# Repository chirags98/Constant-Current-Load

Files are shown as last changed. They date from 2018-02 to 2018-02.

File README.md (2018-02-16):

# Constant-Current-Load

This circuit uses an opamp and a mosfet as a voltage follower circuit. I can dial in any current I want and the circuit will adjust itself to draw that much current from the power supply regardless of the supply voltage. It can be 3 Volts, 5 Volts, 15 Volts whatever it might be and the load will adjust itself to draw the selected current.

This is a double sided board design which I got manufactured from a PCB prototyping firm in China.

I designed the circuit to have the following features

* To have a knob to vary the current from 1mA-2A
* Dissipate upto 30 watts of power
* Connect a supply upto 30 volts
* To have a LCD panel to show 
    * Current drawn
    * Voltage across the load
    * Power dissipated in the load
* Give warnings if power/current/voltage range are excedded
* Give the user the choice to run the circuit from the load supply thereby eliminating the need for an external power supply

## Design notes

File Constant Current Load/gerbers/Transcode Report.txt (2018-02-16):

   ---- Transcoding 'E:\EAGLE 8.2.2\My projects\Constant-Current-Load\Constant Current Load\gerbers\load.GBS' ----   Tue Sep 12 23:22:22 2017

D10   --> D100
D11   --> D101
D12   --> D102
D13   --> D103
D14   --> D104
D15   --> D105
D16   --> D106
D17   --> D107
D18   --> D108
D19   --> D109
D20   --> D110
D21   --> D111
D22   --> D112
D23   --> D113
D24   --> D114
D25   --> D115
D26   --> D116
D27   --> D117
-----------------------------------------------------------------

   ---- Transcoding 'E:\EAGLE 8.2.2\My projects\Constant-Current-Load\Constant Current Load\gerbers\load.GTL' ----   Tue Sep 12 23:22:22 2017

D10   --> D118
D11   --> D119
D12   --> D120
D13   --> D121
D14   --> D122
D15   --> D123
D16   --> D124
D17   --> D125
D18   --> D126
D19   --> D127
D20   --> D128
D21   --> D129
D22   --> D130
D23   --> D131
D24   --> D132
D25   --> D133
D26   --> D134
D27   --> D135
D28   --> D136
D29   --> D137
-----------------------------------------------------------------

   ---- Transcoding 'E:\EAGLE 8.2.2\My projects\Constant-Current-Load\Constant Current Load\gerbers\load.GTO' ----   Tue Sep 12 23:22:22 2017

D10   --> D138
D11   --> D139
D12   --> D140
D13   --> D141
D14   --> D142
D15   --> D143
D16   --> D144
D17   --> D145
D18   --> D146
D19   --> D147
D20   --> D148
D21   --> D149
D22   --> D150
D23   --> D151
D24   --> D152
-----------------------------------------------------------------

   ---- Transcoding 'E:\EAGLE 8.2.2\My projects\Constant-Current-Load\Constant Current Load\gerbers\load.GTS' ----   Tue Sep 12 23:22:22 2017

D10   --> D153
D11   --> D154
D12   --> D155
D13   --> D156
D14   --> D157
D15   --> D158
D16   --> D159
D17   --> D160
D18   --> D161
D19   --> D162
D20   --> D163
D21   --> D164
D22   --> D165
D23   --> D166
D24   --> D167
D25   --> D168
D26   --> D169
D27   --> D170
D28   --> D171
D29   --> D172
D30   --> D173
D31   --> D174
-----------------------------------------------------------------

   ---- Transcoding 'E:\EAGLE 8.2.2\My projects\Constant-Current-Load\Constant Current Load\gerbers\load.GBS' ----   Tue Sep 12 23:25:59 2017

D10   --> D100
D11   --> D101
D12   --> D102
D13   --> D103
D14   --> D104
D15   --> D105
D16   --> D106
D17   --> D107
D18   --> D108
D19   --> D109
D20   --> D110
D21   --> D111
D22   --> D112
D23   --> D113
D24   --> D114
D25   --> D115
D26   --> D116
D27   --> D117
-----------------------------------------------------------------

   ---- Transcoding 'E:\EAGLE 8.2.2\My projects\Constant-Current-Load\Constant Current Load\gerbers\load.GTL' ----   Tue Sep 12 23:25:59 2017

D10   --> D118
D11   --> D119
D12   --> D120
D13   --> D121
D14   --> D122
D15   --> D123
D16   --> D124
D17   --> D125
D18   --> D126
D19   --> D127
D20   --> D128
D21   --> D129
D22   --> D130
D23   --> D131
D24   --> D132
D25   --> D133
D26   --> D134
D27   --> D135
D28   --> D136
D29   --> D137
-----------------------------------------------------------------

   ---- Transcoding 'E:\EAGLE 8.2.2\My projects\Constant-Current-Load\Constant Current Load\gerbers\load.GTO' ----   Tue Sep 12 23:26:00 2017

D10   --> D138
D11   --> D139
D12   --> D140
D13   --> D141
D14   --> D142
D15   --> D143
D16   --> D144
D17   --> D145
D18   --> D146
D19   --> D147
D20   --> D148
D21   --> D149
D22   --> D150
D23   --> D151
D24   --> D152
-----------------------------------------------------------------

   ---- Transcoding 'E:\EAGLE 8.2.2\My projects\Constant-Current-Load\Constant Current Load\gerbers\load.GTS' ----   Tue Sep 12 23:26:00 2017

D10   --> D153
D11   --> D154
D12   --> D155
D13   --> D156
D14   --> D157
D15   --> D158
D16   --> D159
D17   --> D160
D18   --> D161
D19   --> D162
D20   --> D163
D21   --> D164
D22   --> D165
D23   --> D166
D24   --> D167
D25   --> D168
D26   --> D169
D27   --> D170
D28   --> D171
D29   --> D172
D30   --> D173
D31   --> D174
-----------------------------------------------------------------

   ---- Transcoding 'E:\EAGLE 8.2.2\My projects\Constant-Current-Load\Constant Current Load\gerbers\load.GBS' ----   Tue Sep 12 23:31:38 2017

D10   --> D100
D11   --> D101
D12   --> D102
D13   --> D103
D14   --> D104
D15   --> D105
D16   --> D106
D17   --> D107
D18   --> D108
D19   --> D109
D20   --> D110
D21   --> D111
D22   --> D112
D23   --> D113
D24   --> D114
D25   --> D115
D26   --> D116
D27   --> D117
-----------------------------------------------------------------

   ---- Transcoding 'E:\EAGLE 8.2.2\My projects\Constant-Current-Load\Constant Current Load\gerbers\load.GTL' ----   Tue Sep 12 23:31:38 2017

D10   --> D118
D11   --> D119
D12   --> D120
D13   --> D121
D14   --> D122
D15   --> D123
D16   --> D124
D17   --> D125
D18   --> D126
D19   --> D127
D20   --> D128
D21   --> D129
D22   --> D130
D23   --> D131
D24   --> D132
D25   --> D133
D26   --> D134
D27   --> D135
D28   --> D136
D29   --> D137
-----------------------------------------------------------------

   ---- Transcoding 'E:\EAGLE 8.2.2\My projects\Constant-Current-Load\Constant Current Load\gerbers\load.GTO' ----   Tue Sep 12 23:31:38 2017

D10   --> D138
D11   --> D139
D12   --> D140
D13   --> D141
D14   --> D142
D15   --> D143
D16   --> D144
D17   --> D145
D18   --> D146
D19   --> D147
D20   --> D148
D21   --> D149
D22   --> D150
D23   --> D151
D24   --> D152
-----------------------------------------------------------------

   ---- Transcoding 'E:\EAGLE 8.2.2\My projects\Constant-Current-Load\Constant Current Load\gerbers\load.GTS' ----   Tue Sep 12 23:31:38 2017

D10   --> D153
D11   --> D154
D12   --> D155
D13   --> D156
D14   --> D157
D15   --> D158
D16   --> D159
D17   --> D160
D18   --> D161
D19   --> D162
D20   --> D163
D21   --> D164
D22   --> D165
D23   --> D166
D24   --> D167
D25   --> D168
D26   --> D169
D27   --> D170
D28   --> D171
D29   --> D172
D30   --> D173
D31   --> D174
-----------------------------------------------------------------

   ---- Transcoding 'E:\EAGLE 8.2.2\My projects\Constant-Current-Load\Constant Current Load\gerbers\load.GBS' ----   Tue Sep 12 23:42:00 2017

D10   --> D100
D11   --> D101
D12   --> D102
D13   --> D103
D14   --> D104
D15   --> D105
D16   --> D106
D17   --> D107
D18   --> D108
D19   --> D109
D20   --> D110
D21   --> D111
D22   --> D112
D23   --> D113
D24   --> D114
D25   --> D115
D26   --> D116
D27   --> D117
-----------------------------------------------------------------

   ---- Transcoding 'E:\EAGLE 8.2.2\My projects\Constant-Current-Load\Constant Current Load\gerbers\load.GTL' ----   Tue Sep 12 23:42:01 2017

D10   --> D118
D11   --> D119
D12   --> D120
D13   --> D121
D14   --> D122
D15   --> D123
D16   --> D124
D17   --> D125
D18   --> D126
D19   --> D127
D20   --> D128
D21   --> D129
D22   --> D130
D23   --> D131
D24   --> D132
D25   --> D133
D26   --> D134
D27   --> D135
D28   --> D136
D29   --> D137
-----------------------------------------------------------------

   ---- Transcoding 'E:\EAGLE 8.2.2\My projects\Constant-Current-Load\Constant Current Load\gerbers\load.GTO' ----   Tue Sep 12 23:42:01 2017

D10   --> D138
D11   --> D139
D12   --> D140
D13   --> D141
D14   --> D142
D15   --> D143
D16   --> D144
D17   --> D145
D18   --> D146
D19   --> D147
D20   --> D148
D21   --> D149
D22   --> D150
D23   --> D151
-----------------------------------------------------------------

   ---- Transcoding 'E:\EAGLE 8.2.2\My projects\Constant-Current-Load\Constant Current Load\gerbers\load.GTS' ----   Tue Sep 12 23:42:01 2017

D10   --> D152
D11   --> D153
D12   --> D154
D13   --> D155
D14   --> D156
D15   --> D157
D16   --> D158
D17   --> D159
D18   --> D160
D19   --> D161
D20   --> D162
D21   --> D163
D22   --> D164
D23   --> D165
D24   --> D166
D25   --> D167
D26   --> D168
D27   --> D169
D28   --> D170
D29   --> D171
D30   --> D172
D31   --> D173
-----------------------------------------------------------------

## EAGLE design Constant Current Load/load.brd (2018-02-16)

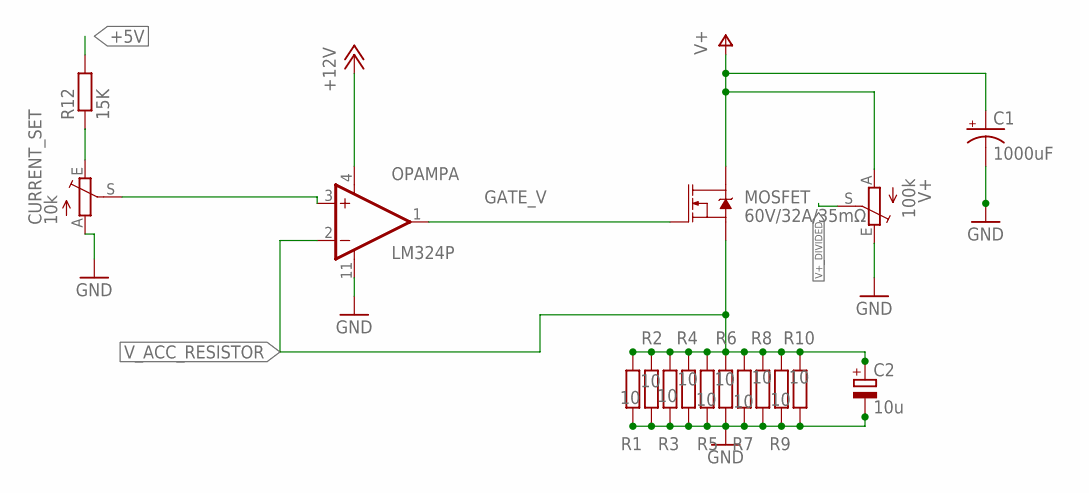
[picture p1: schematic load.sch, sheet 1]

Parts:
C1: 1000uF; CPOL-RADIAL-5MM-10MM
C2: 10u; E2,5-6E
CURRENT_SET: 10k; S64W
MOSFET: 60V/32A/35mΩ; TO220V
OPAMP: LM324P; DIL14
R1, R2, R3, R4, R5, R6, R7, R8, R9, R10: 10; 0207/12
R12: 15K; M0805
V+: 100k; S64W

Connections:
+5V: R12.2; also elsewhere on the board
+12V: OPAMP.4 (V+); also elsewhere on the board
GATE_V: MOSFET.1 (G), OPAMP.1 (OUT); also elsewhere on the board
GND: C1.-, C2.-, CURRENT_SET.A, OPAMP.11 (V-), R1.1, R2.1, R3.1, R4.1, R5.1, R6.1, R7.1, R8.1, R9.1, R10.1, V+.E; also elsewhere on the board
unnamed: CURRENT_SET.S, OPAMP.3 (+IN)
unnamed: CURRENT_SET.E, R12.1
V+: C1.+, MOSFET.2 (D), V+.A; also elsewhere on the board
V+_DIVIDED: V+.S; also elsewhere on the board
V_ACC_RESISTOR: C2.+, MOSFET.3 (S), OPAMP.2 (-IN), R1.2, R2.2, R3.2, R4.2, R5.2, R6.2, R7.2, R8.2, R9.2, R10.2; also elsewhere on the board

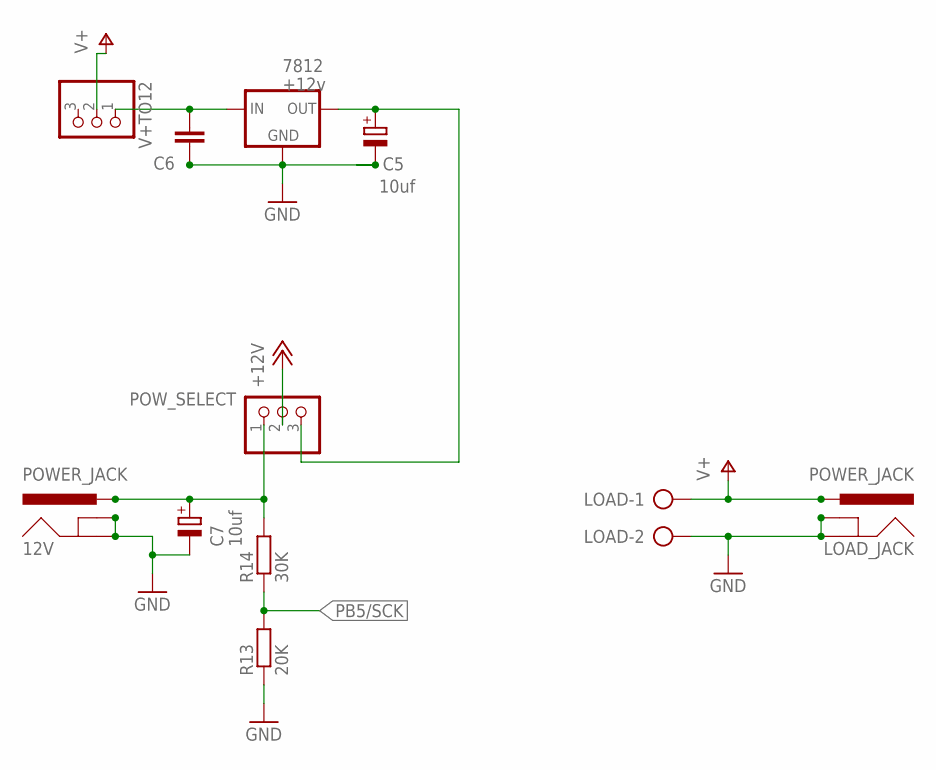
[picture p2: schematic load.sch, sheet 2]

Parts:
12V: POWER_JACK; POWER_JACK_PTH
7812: +12v; TO-252
C5, C7: 10uf; E2,5-6
C6: .1uF; C0805K
LOAD: AK500/2-H
LOAD_JACK: POWER_JACK; POWER_JACK_PTH
POW_SELECT: PINHD-1X3; 1X03
R13: 20K; M0805
R14: 30K; M0805
V+TO12: PINHD-1X3; 1X03

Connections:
12V_JACK_INPUT: 12V.PWR, C7.+, POW_SELECT.1, R14.2
12V_REG_O/P: 7812.2 (OUT), C5.+, POW_SELECT.3
+12V: POW_SELECT.2; also elsewhere on the board
GND: 12V.GND, 12V.GNDBREAK, 7812.3 (GND), C5.-, C6.2, C7.-, LOAD.2, LOAD_JACK.GND, LOAD_JACK.GNDBREAK, R13.1; also elsewhere on the board
unnamed: 7812.1 (IN), C6.1, V+TO12.1
PB5/SCK: R13.2, R14.1; also elsewhere on the board
V+: LOAD.1, LOAD_JACK.PWR, V+TO12.2; also elsewhere on the board

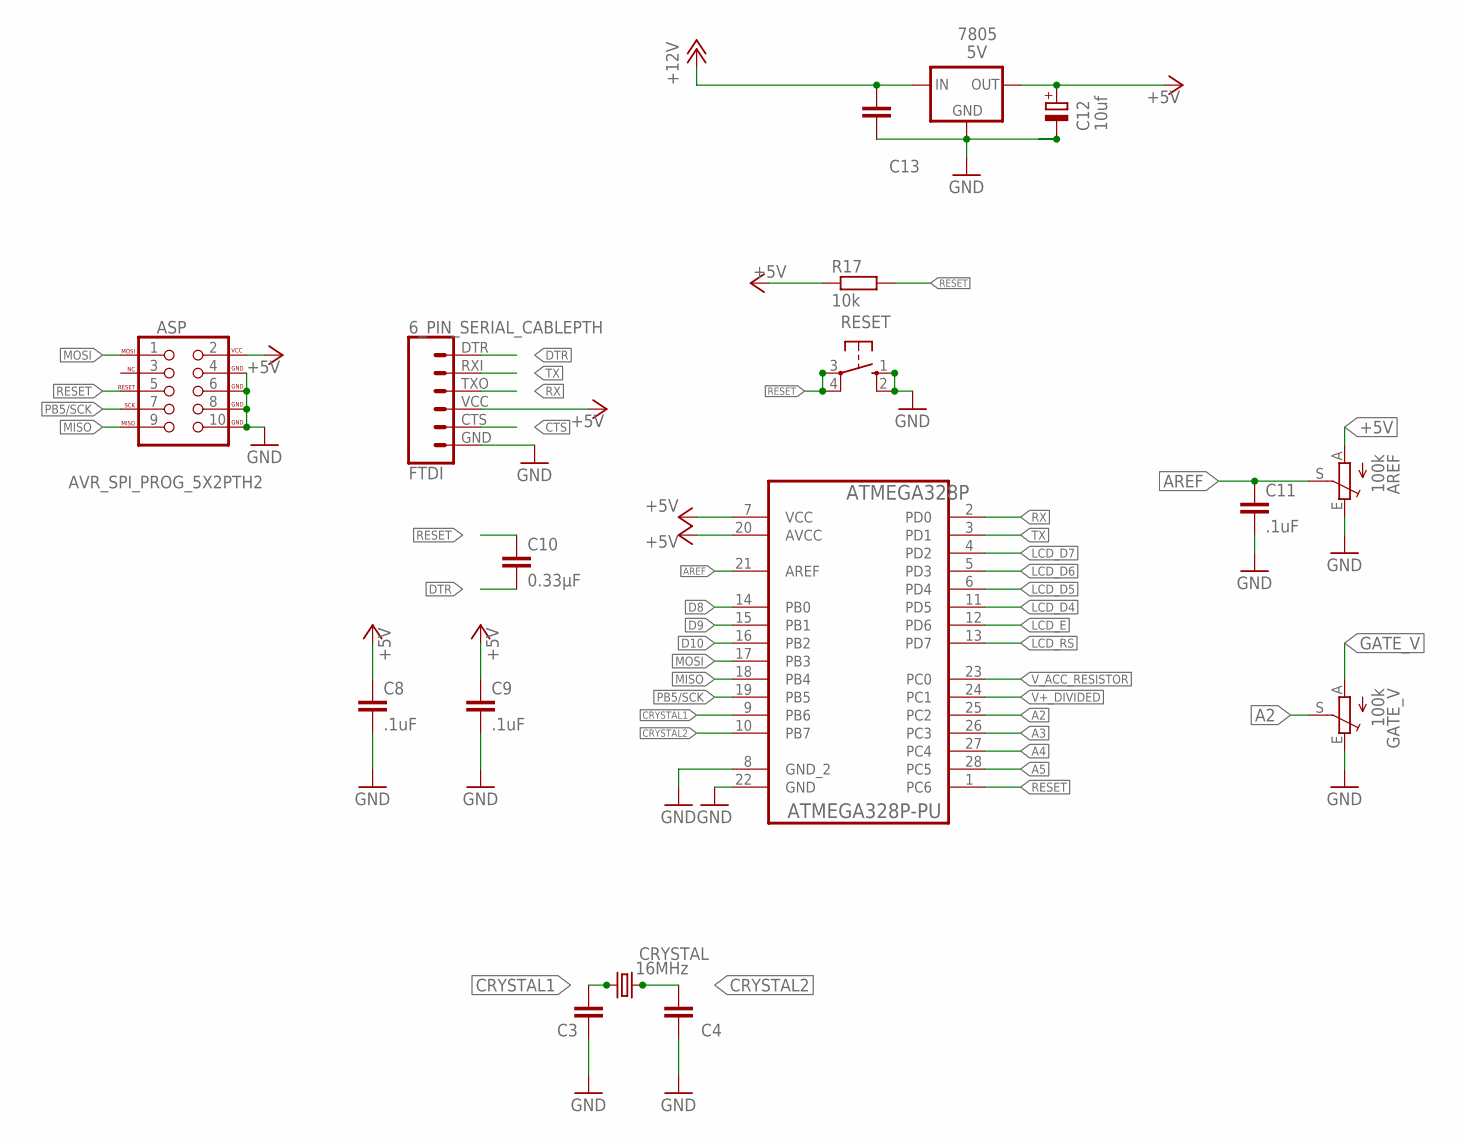
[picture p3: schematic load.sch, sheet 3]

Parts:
7805: 5V; TO-252
AREF: 100k; S64W
ASP: AVR_SPI_PROG_5X2PTH2; 2X5-SHROUDED
ATMEGA328P: ATMEGA328P-PU; DIP254P762X457-28
C3, C4: 22pF; C0805K
C8, C9, C11: .1uF; C0805K
C10: 0.33µF; C0805K
C12: 10uf; E2,5-6
C13: .1uf; C0805K
CRYSTAL: 16MHz; HC49U70
FTDI: 6_PIN_SERIAL_CABLEPTH; FTDI_BASIC
GATE_V: 100k; S64W
R17: 10k; M0805
RESET: 10-XX; B3F-10XX

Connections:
+5V: 7805.2 (OUT), AREF.A, ASP.2 (VCC), ATMEGA328P.7 (VCC), ATMEGA328P.20 (AVCC), C8.1, C9.1, C12.+, FTDI.VCC (4), R17.1; also elsewhere on the board
+12V: 7805.1 (IN), C13.1; also elsewhere on the board
A2: ATMEGA328P.25 (PC2), GATE_V.S
A3: ATMEGA328P.26 (PC3)
A4: ATMEGA328P.27 (PC4)
A5: ATMEGA328P.28 (PC5)
AREF: AREF.S, ATMEGA328P.21 (AREF), C11.1
CRYSTAL1: ATMEGA328P.9 (PB6), C3.2, CRYSTAL.1
CRYSTAL2: ATMEGA328P.10 (PB7), C4.2, CRYSTAL.2
CTS: FTDI.CTS (5)
D8: ATMEGA328P.14 (PB0)
D9: ATMEGA328P.15 (PB1)
D10: ATMEGA328P.16 (PB2)
DTR: C10.2, FTDI.DTR (1)
GATE_V: GATE_V.A; also elsewhere on the board
GND: 7805.3 (GND), AREF.E, ASP.4 (GND), ASP.6 (GND), ASP.8 (GND), ASP.10 (GND), ATMEGA328P.8 (GND_2), ATMEGA328P.22 (GND), C3.1, C4.1, C8.2, C9.2, C11.2, C12.-, C13.2, FTDI.GND (6), GATE_V.E, RESET.1 (S), RESET.2 (S1); also elsewhere on the board
LCD_D4: ATMEGA328P.11 (PD5); also elsewhere on the board
LCD_D5: ATMEGA328P.6 (PD4); also elsewhere on the board
LCD_D6: ATMEGA328P.5 (PD3); also elsewhere on the board
LCD_D7: ATMEGA328P.4 (PD2); also elsewhere on the board
LCD_E: ATMEGA328P.12 (PD6); also elsewhere on the board
LCD_RS: ATMEGA328P.13 (PD7); also elsewhere on the board
MISO: ASP.9 (MISO), ATMEGA328P.18 (PB4)
MOSI: ASP.1 (MOSI), ATMEGA328P.17 (PB3)
PB5/SCK: ASP.7 (SCK), ATMEGA328P.19 (PB5); also elsewhere on the board
RESET: ASP.5 (RESET), ATMEGA328P.1 (PC6), C10.1, R17.2, RESET.3, RESET.4 (P1)
RX: ATMEGA328P.2 (PD0), FTDI.TXO (3)
TX: ATMEGA328P.3 (PD1), FTDI.RXI (2)
V+_DIVIDED: ATMEGA328P.24 (PC1); also elsewhere on the board
V_ACC_RESISTOR: ATMEGA328P.23 (PC0); also elsewhere on the board

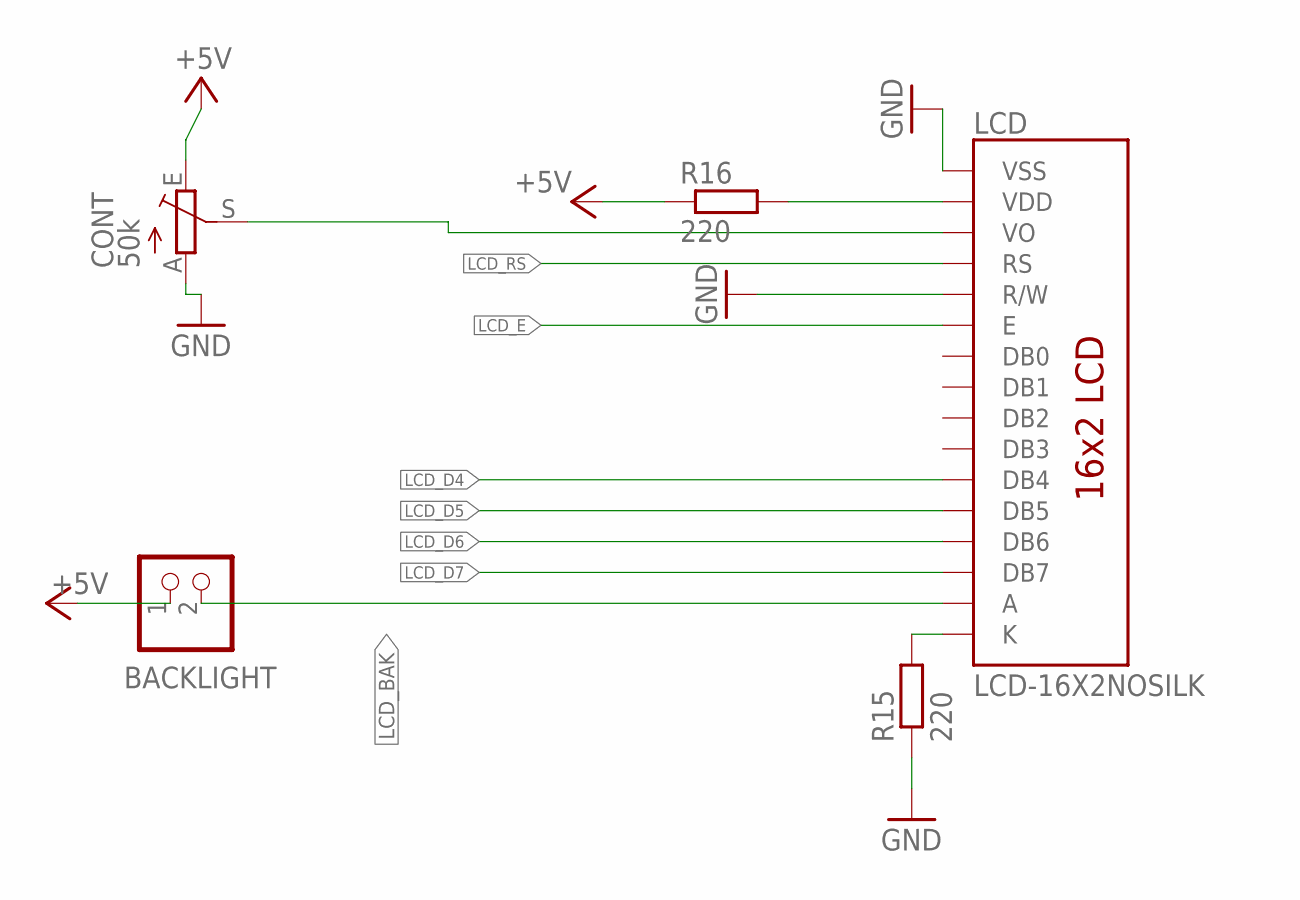
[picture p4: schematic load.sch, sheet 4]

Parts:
BACKLIGHT: PINHD-1X2; 1X02
CONT: 50k; S64W
LCD: LCD-16X2NOSILK; LCD-16X2_NOSILK
R15, R16: 220; M0805

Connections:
+5V: BACKLIGHT.1, CONT.E, R16.1; also elsewhere on the board
GND: CONT.A, LCD.1 (VSS), LCD.5 (R/W), R15.1; also elsewhere on the board
LCD_BAK: BACKLIGHT.2, LCD.15 (A)
LCD_D4: LCD.11 (DB4); also elsewhere on the board
LCD_D5: LCD.12 (DB5); also elsewhere on the board
LCD_D6: LCD.13 (DB6); also elsewhere on the board
LCD_D7: LCD.14 (DB7); also elsewhere on the board
LCD_E: LCD.6 (E); also elsewhere on the board
LCD_RS: LCD.4 (RS); also elsewhere on the board
unnamed: CONT.S, LCD.3 (VO)
unnamed: LCD.2 (VDD), R16.2
unnamed: LCD.16 (K), R15.2

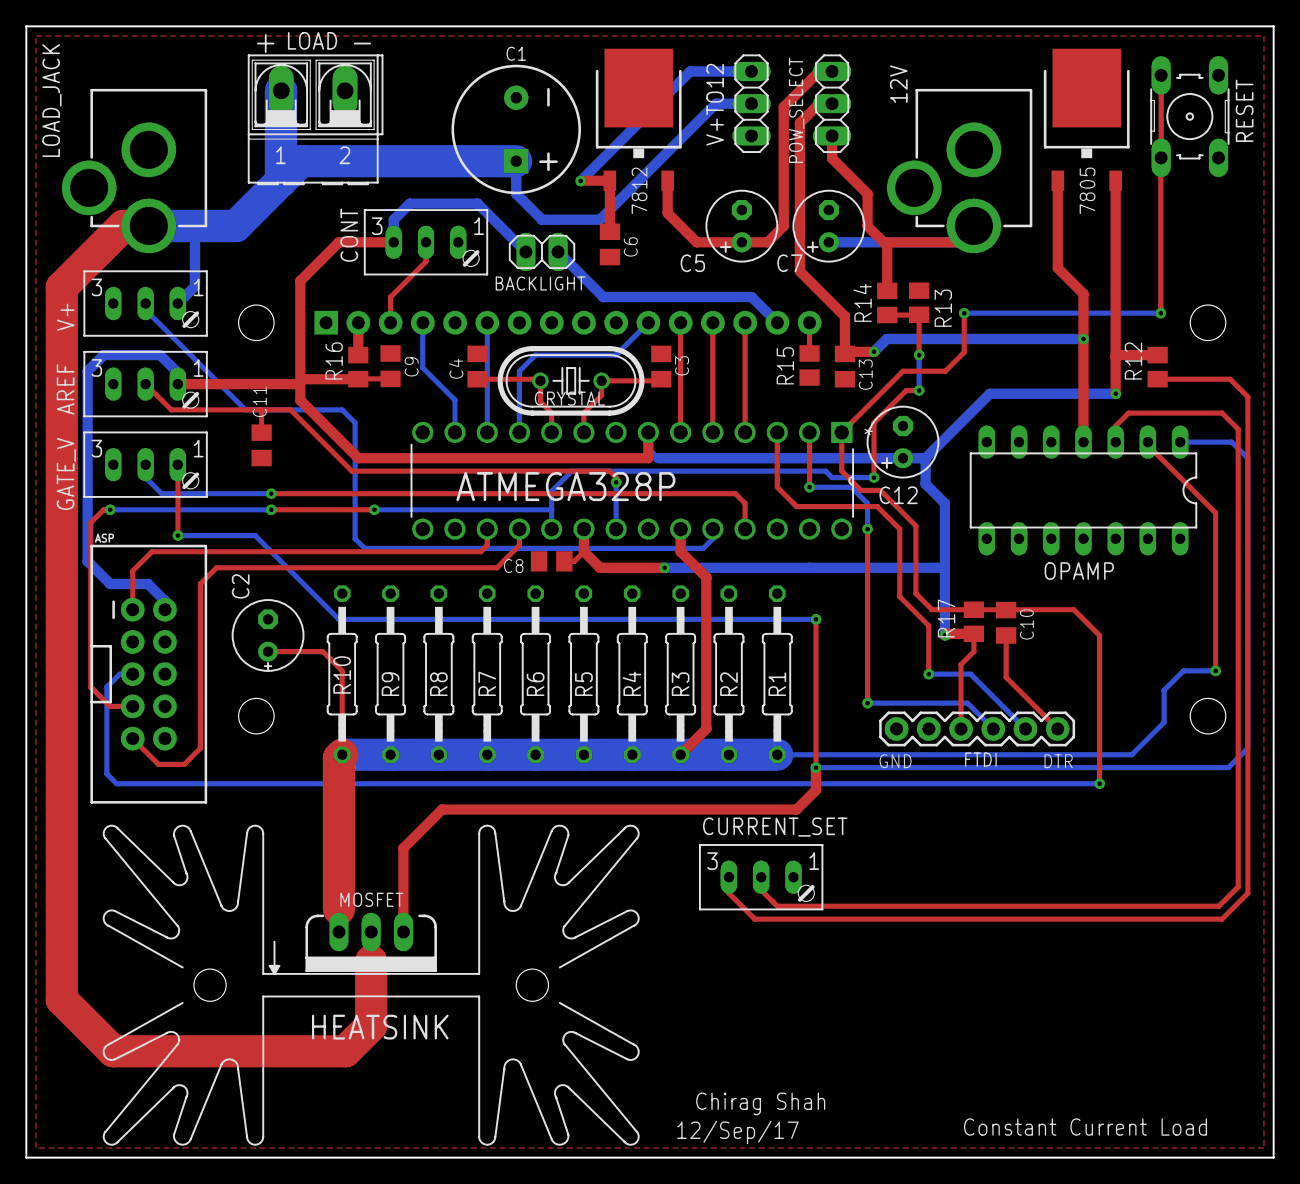
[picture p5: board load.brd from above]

Board: 2 copper layers, 98.3 x 89.2 mm, 51 parts (0 on the bottom side), 33 nets.

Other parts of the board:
HEATSINK: SK129-HOLE

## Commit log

2017-07-22 Pushing latest version
    [load.brd, load.sch]
2017-08-29 Starting work on double sided board
    [load.brd, load.sch]
2017-09-02 Replaced through hole with smd
    [load.brd, load.sch]
2017-09-02 Routed the pcb v1
    [load.brd]
2017-09-08 Still working
    [load.brd, load.sch]
2017-09-11 Complete I guess
    [load.brd, load.sch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]
2017-09-12 Before moving HS and Pot
    [load.brd, load.sch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]

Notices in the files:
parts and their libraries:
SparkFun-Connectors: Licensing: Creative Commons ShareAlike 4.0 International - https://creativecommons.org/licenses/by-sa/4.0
